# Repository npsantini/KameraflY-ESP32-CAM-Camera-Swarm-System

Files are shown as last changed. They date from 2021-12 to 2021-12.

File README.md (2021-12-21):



# KameraflY

<table width="100%">
    <tr>
	    <td width="33.33%"></td>
	    <td width="33.33%">
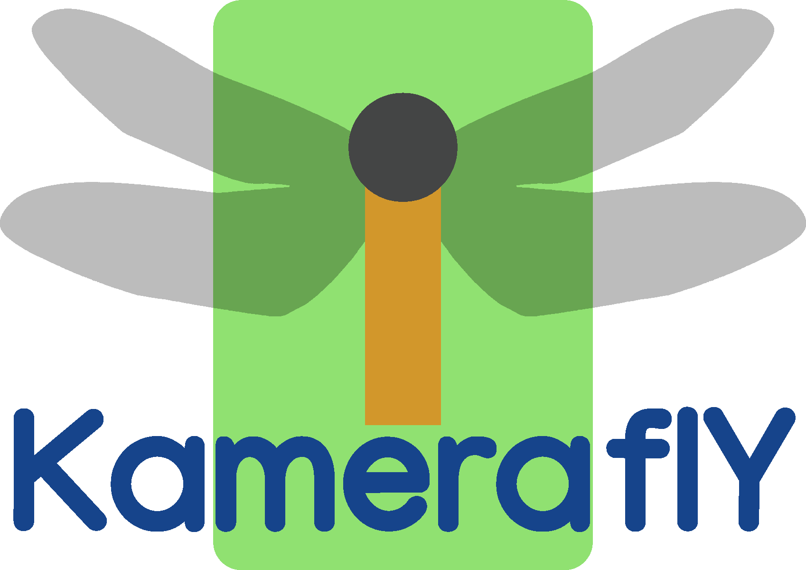
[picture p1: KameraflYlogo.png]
camerafly logo
		    
	    </td>
	    <td width="33.33%"></td>
    </tr>
</table>

## Contents
- <a href="#firmware">Overview</a>
- <a href="#firmware">ESP32-CAM Firmware</a>
    - <a href="#arduino">Arduino IDE</a>
    - <a href="#libraries">Libraries</a>
    - <a href="#functions">Functions</a>
    - <a href="#firmware-improvement">Potential Improvements</a>
- <a href="#blynk">Blynk App</a>
    - <a href="#setup">Setup</a>
    - <a href="#components">Components</a>
    - <a href="#blynk-improvement">Potential Improvements</a>
- <a href="#web">Web App</a>
    - <a href="#requirements">Requirements</a>
    - <a href="#web-improvement">Potential Improvements</a>
- <a href="#pcb">PCB Info</a>
	- <a href="#pcb-improvement">Potential Improvements</a>
- <a href="#housing">Housing</a>
	- <a href="#housing-improvement">Potential Improvements</a>
- <a href="#parts">Parts</a>
	- <a href="#partslist">Parts List</a>
	- <a href="#parts-improvement">Potential Improvements</a>

<hr>
<!-- Overview -->

### Overview
<hr>
<p>
Our current ESP32-CAM camera swarm is a completly wireless swarm that is capable of caturing synchronized images down to 10ms.
The system we have created allows a user to use and Android or iOS app to control the camera swarm. When images are captured they 
are sent to a web server where all of the images can be downloaded at once. The images collected from the web server can be used 
in many different applications like 3D modeling or for use in 3D point cloud software.</p>

<p>Each of our completed modules costs only $13.43. When scaled to 256 modules the cost $6.96 per module. This makes this camera swarm 
an extremely cost effective tool that is a lot more accessible than traditional DSLR focused camera swarms.</p>

<p align="right">(<a href="#top">back to top</a>)</p>
<hr>
<!-- ESP32-CAM Firmware -->

### ESP32-CAM Firmware
<hr>
The ESP32-CAM modules in our swarm were all programmed to work with the Blynk app. This was mainly due to time constraints and the ease of use. It is setup in a way to perform only a few actions like connect to the Blynk app, save images to an SD card, upload an image via FTP, and live stream video. There are improvements that can be made and it's far from perfect. It satisfied our engineering requirements, which is all we had set out to accomplish.

I encourage anyone that would like to continue this to fork this repository or make pull requests.

#### Arduino IDE
The Arduino IDE is what was used for ease of use. It is possible to also use <a href="https://platform.io" target="_blank">PlatformIO</a> although we have not tested it.
It's important to include all of the libraries that you will see in the next section. It is also important that in the change the information in the <a href="#">secrets.h</a> file.
```C++
// secrets.h file
#define SECRET_SSID "INSERT WIFI SSID HERE"
#define SECRET_PASSWORD "INSERT WIFI PASSWORD HERE"

#define SECRET_FTP_SERVER "INSERT FTP SERVER IP ADDRESS HERE"
#define SECRET_FTP_USERNAME "INSERT FTP USERNAME HERE" // ex. user@example.com
#define SECRET_FTP_PASSWORD "INSERT FTP PASSWORD"
```

#### Libraries
In order to include all of the necessary libraries for the ESP32-CAM's you need to 
add the following additional board manager in the Arduino IDE under `File > Preferences`:
<br>
```
https://raw.githubusercontent.com/espressif/arduino-esp32/gh-pages/package_esp32_index.json
```

##### Included packages from the source above:
- SD_MMC
- WebServer
- EEPROM
- FS
- WiFi
- And more.

You might have conflicting wifi libraries. You will have to fix this by removing one of the libraries that the error message lists.

##### Libraries in Arduino Library Manager
- Blynk (Volodymyr Shymanskyy) v0.6.1
- esp32_ftpclient (Leonardo Bispo) v0.1.4
- SD (Arduino) v1.2.4
- Time (Paul Stoffregen) v1.6.1

#### Functions
- Live Stream Functions (Anatoli Arkhipenko, https://github.com/arkhipenko/esp32-cam-mjpeg)
	- handle_jpg_stream(void)
	- handle_jpg()
	- handleNotFound()
- SD Card Functions (Rui Santos, https://RandomNerdTutorials.com/esp32-cam-take-photo-save-microsd-card)
	- SD_MMC.begin() // Check to see if sd card is mounted
	- SD_MMC.cardType() // Check card type
- FTP Functions
	- FTP_upload(void)
- Main Logic Functions
	- setup()
	- loop()
	- take_picture()
- Blynk Functions/Methods
	- Blynk.run()
	- BLYNK_CONNECTED()
	- BLYNK_WRITE(V5)
	- BLYNK_WRITE(V10)
	- BLYNK_WRITE(V12)
	- BLYNK_WRITE(V14)
- Misc. Functions
	- deep_sleep()
	- ipAddress2String(const IPAddress& ipAddress)

#### Potential Improvements

<p>
This firmware for the ESP32-CAM is not perfect. We encourage people make improvements as they see fit. Most of the code is to be specifically used with the Blynk Legacy mobile app. If you wish to use your own app it would need to be changed substantially.
</p>
<p>
One big improvement would be programming the ESP32-CAM modules to take an image at a specified time. This is something we were not able to accomplish with the current version of the Blynk app, but will be coming soon as dicussed in more detail below.
</p>

<p align="right">(<a href="#top">back to top</a>)</p>
<hr>

<!-- Blynk App -->

### Blynk App
<hr>
<p>
We chose to use the Legacy Blynk app to control our ESP32-CAM camera swarm. It's not a perfect solution, but is much more convenient than writing your own app to fulfill the same functionality. There are a lot of great things you can do with the Blynk app, however we have chosen to use what we believe to be the bare essentials necessary to control and effectively use the camera swarm.
</p>

#### Setup
<p>Below are some images of the basic setup of each ESP32-CAM module and how to add all of the modules to one tag. In this case, we named the tag "All",
but you could name it whatever you like. Having all of the modules with the same tag allows us to use one button to capture all of the images from each of the cameras in the camera swarm simultaneously.</p>

<table>
    <tr>
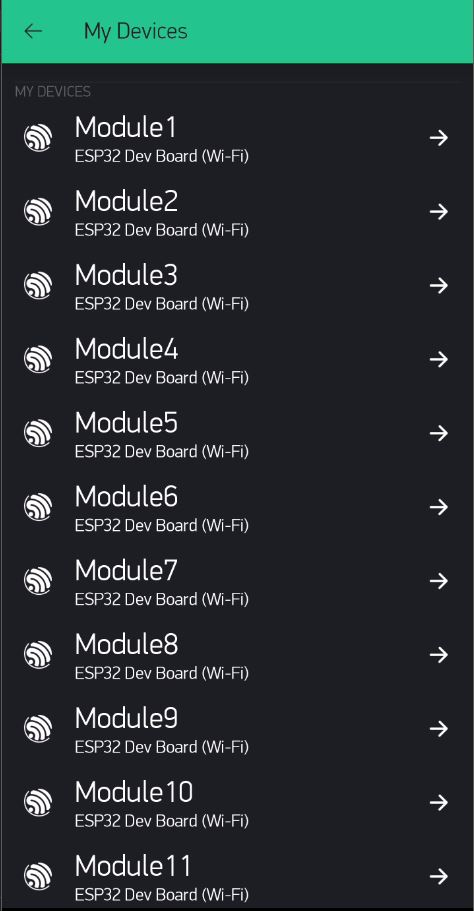
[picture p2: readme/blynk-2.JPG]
        <td width="20%"></td>
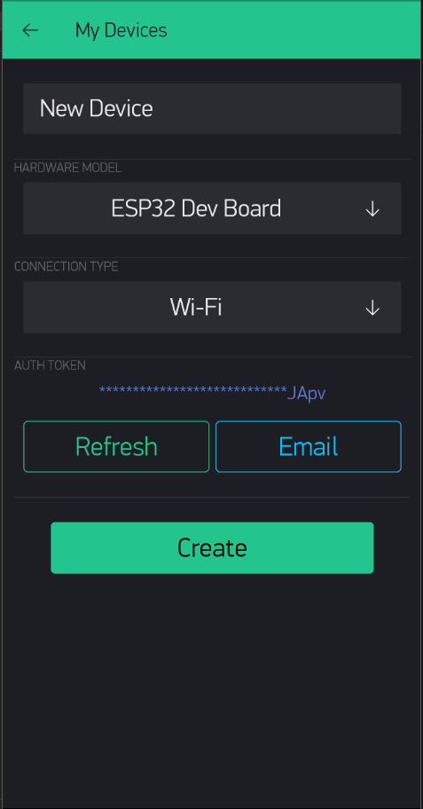
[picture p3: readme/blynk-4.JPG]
        <td width="20%"></td>
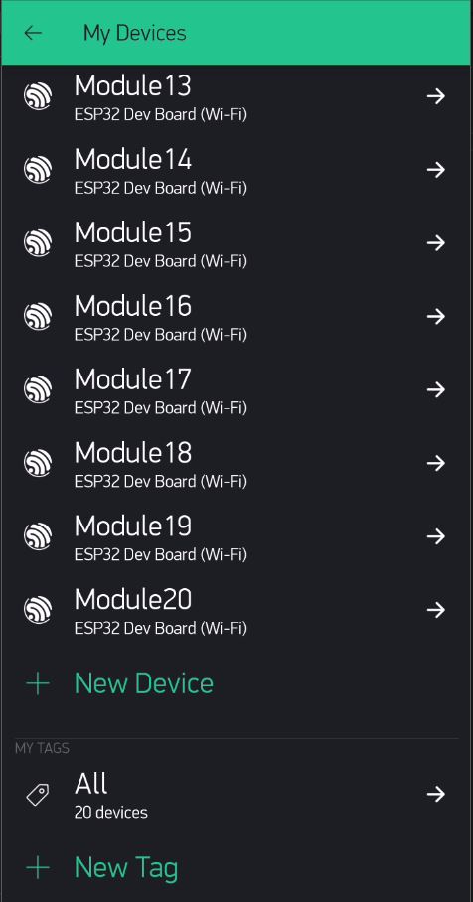
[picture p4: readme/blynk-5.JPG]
        <td width="20%"></td>
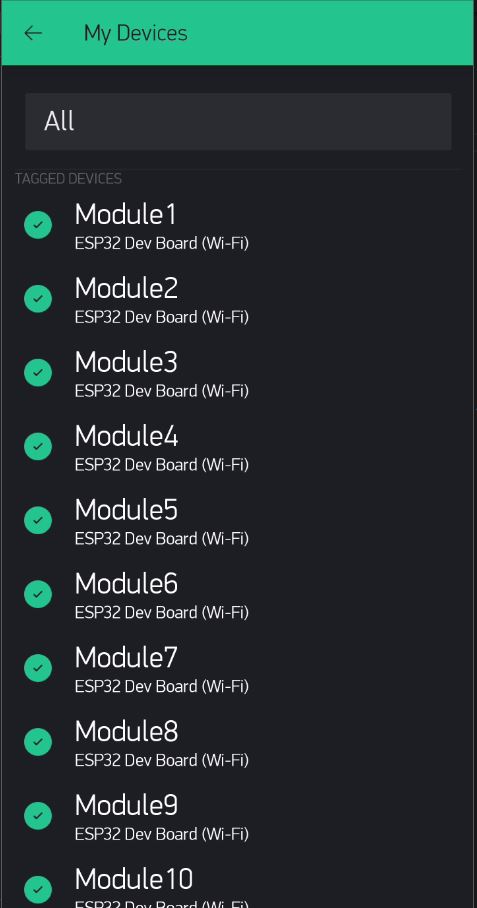
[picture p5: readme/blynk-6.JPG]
        <td width="20%"></td>
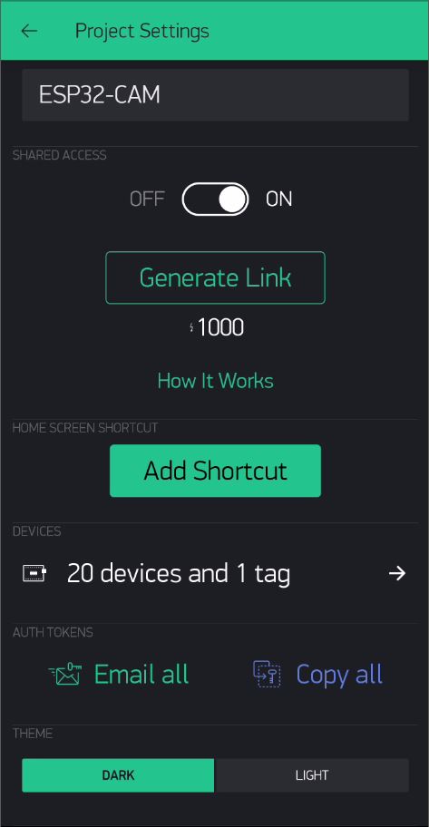
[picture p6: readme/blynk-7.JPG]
        <td width="20%"></td>
    </tr>
    <tr>
	    <td valign="top" width="20%">
		    <p>- Go to "My Devices."</p>
		    <p>- Scroll down and click "+ New Device."</p>
	    </td>
	    <td valign="top" width="20%">
		    <p>- Name the module (numbers help identify the module later).</p>
		    <p>- Select "ESP32 Dev Board.</p>
		    <p>- Choose "Wi-Fi".</p>
		    <p>- Click "Create".</p>
	    </td>
	    <td valign="top" width="20%">
		    <p>- You will then see a list of modules that you have created.</p>
		    <p>- Now create a new tag by clicking "+ New Tag"</p>
	    </td>
	    <td valign="top" width="20%">
		    <p>- Name the tag "All"</p>
		    <p>- Once created check off all of the modules you want to add to the tag.</p>
	    </td>
	    <td valign="top" width="20%">
		    <p>- In the project settings click "Email all" to get all of the Authorization tokens that you will need to include in the firmware.</p>
	    </td>
    </tr>
</table>
<p>
The most important part of the setup is that you get all of the Authorization tokens (emailing them from the app is easiest) and add them to the section of code below. Make sure you only have one authorization token uncommented at a time. For each ESP32-CAM that you program you need to uncomment a new token and change the `cam_module` number to the current module you are using. This will allow you to identify which module each picture came from and helps with troubleshooting the modules.
</p>

```c++
String cam_module = "4"; 
//char auth[] = "MODULE 1 AUTH TOKEN HERE"; //1
//char auth[] = "MODULE 2 AUTH TOKEN HERE"; //2
//char auth[] = "MODULE 3 AUTH TOKEN HERE"; //3
char auth[] = "MODULE 4 AUTH TOKEN HERE"; //4
//char auth[] = "MODULE 5 AUTH TOKEN HERE"; //5
// etc...
```

#### Components
<p>While we chose to use these specific components to accomplish what we needed to accomplish, you can choose what you you need and can remove the rest. Just make sure to remove the code for components that you aren't using.</p>
<table>
	<tr>
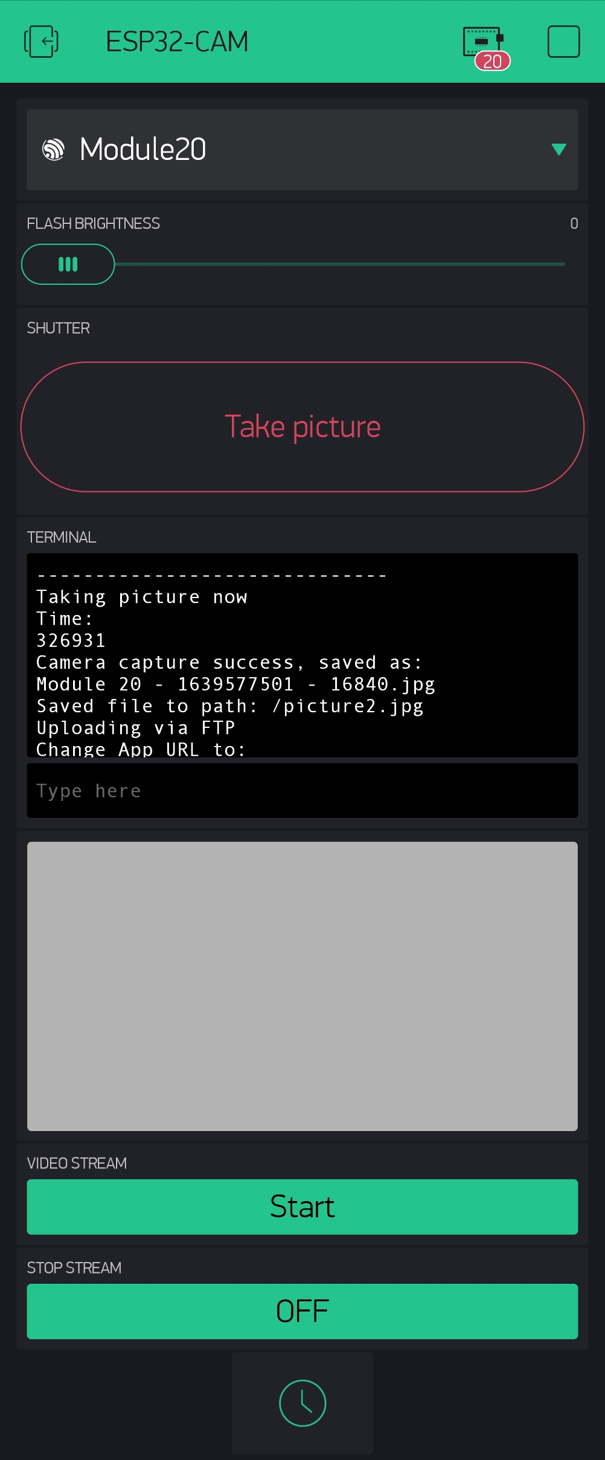
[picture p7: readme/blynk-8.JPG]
		<td width="40%"></td>
		<td width="60%">
	
- Device Selector

- Slider
	- Target: selector
	- Output: 0 - 4
	- Pin: V10

- Button
	- Target: All tag
	- Output: 0 - 1
	- Pin: V5

- Terminal
	- Target: Selector
	- Add Newline: Yes
	- Autoscroll: Yes
	- Pin: V0

- Video Stream
	- Target: Selector
	- URL: 
	- Pin: V13

- Styled Button (Video Stream Start)
	- Target: Selector
	- Output: 0 - 1
	- Pin: V12

- Styled Button (Video Stream Stop)
	- Target: All tag
	- Output: 0 - 1
	- Pin: V14

- Real-time Clock
	- Timezone: (Whatever you wish to use)

		</td>
	</tr>
</table>

#### Potential Improvements
<p>There are improvements coming to the Blynk app that will allow for all of the components to be controlled via the Blynk Cloud web dashboard. This would greatly improve the usability and would elimintate the need to use a mobile phone. Being able to send specific signals such as a time in order to schedule an image capture would greatly improve the synchronization times of the images. We have been told that a lot of this functionality should arrive in Q2 2022.
</p>
<p>Until then we highly recommend using the Legacy Blynk app and not the Blynk IoT app.</p>

<p align="right">(<a href="#top">back to top</a>)</p>
<hr>

<!-- Web App -->

### Web App
<hr>
<p>
The web app that we have included in this is a PHP site displays the last images captured as well as images by each module. It is very basic, but allows you to collect all of the images in a zip file which is extremely useful when you need to import the images in other programs.
</p>

<p>
The login system is something that was added to make sure that people couldn't see the images that were captured unless they had a login. For this specific demo we have a default user and an admin user. Only the admin user has the ability to delete images.
</p>

<p>
<b>It is highly recommended that you change these usernames and passwords!</b>
</p>

- Default User
	- Username: user
	- Password: password

- Admin User
	- Username: admin
	- Password: password

<p>The usernames and passwords are defined as seen below in an array in the `login.php` page and should be changed.</p>

```PHP
$logins = array('admin' => 'password','user' => 'password');
```

#### Requirements

- Web Server
	- Apache
	- PHP v7.0 (or later)
- Optional
	- Web hosting
	- Domain name

#### Potential Improvements
<p>A better way of sorting the images would make this a lot better. Right now it relies on the file name of the images to sort them. This is obviously not ideal.</p>

<p align="right">(<a href="#top">back to top</a>)</p>
<hr>

<!-- PCB Info -->

### PCB Info
<hr>
<table>
	<tr>
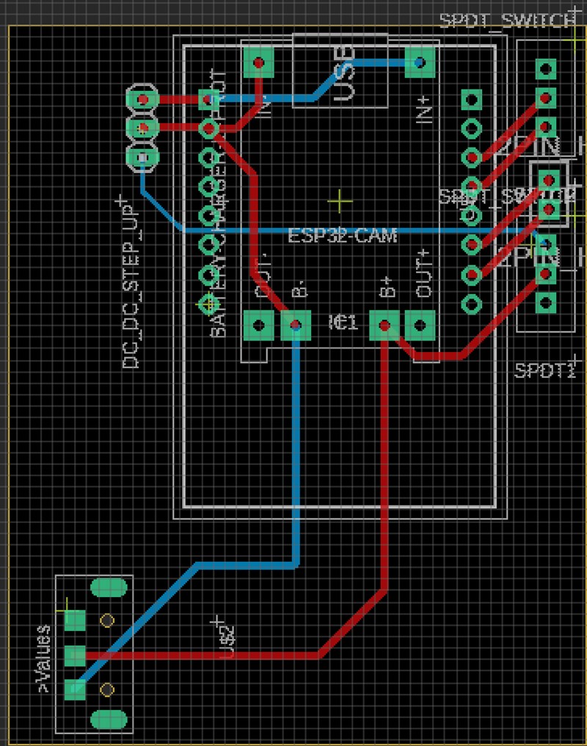
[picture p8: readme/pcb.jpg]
		<td width="25%"></td>
		<td width="75%">
			<p>The PCB subsystem was created to connect all components used for each module together so they are compact, and set up and transport easily. The PCB reduces the need for wires allowing the casing to be smaller. The PCB has dimensions of 50mm X 55mm. There is a switch in the circuit that will turn power off to the ESP32-CAM saving power.</p>
			<p>The routing on the board connects the output of the battery charger to the battery and then to the boost converter. This will increase the voltage from ~3.7V, the voltage of the battery, to 5V, a useful voltage for the ESP32-CAM. This circuit is also ran through a switch that allows the unit to be put in standby mode to save charge. Another switch is connected to two pins of the ESP32-CAM so they can be shorted out to place the camera in programming mode. The 2-pin header is to provide access to the camera for programming purposes.</p>
		</td>
	</tr>
</table>

#### Potential Improvements

<p>
We went through 5 different iterations of the PCB which can be found in the `pcb-shematic` folder. Many of the changes from version to version were to make the footprint as small as possible and to make changes to the battery connector. The battery connector is a part that likely needs to be changed with a better connector for the battery we used. Since we couldn't find the exact battery connector we made our own part in Autodesk Eagle.
</p>
<p>
It's highly recommended that you use these PCB schematics as a starting point for your own, unless you use the exact same parts as we did.
</p>
<p align="right">(<a href="#top">back to top</a>)</p>
<hr>

<!-- Housing -->

### Housing
<hr>

<table>
	<tr>
		<td width="100%">
			<p>The housing is designed so the ESP32-CAM modules can be easily transported and handled comfortably. The housing includes at least 2 different types of mounting to allow for a variety of ways to setup the system. The two chosen were a Keyhole hanger and two tripod mounts. The case allows for access to the removable battery, the removable SD Card, the charging port for the battery, and the various switches used for power and low power mode. The most recent housing is 72 x 58 x 25 mm which is considered "handheld" and fits the components comfortably.
			</p>
			<p>The drafts of the housing and Autodesk Inventor files can be found in the `ESP32-CAM Housing` folder. 
			</p>
		</td>
	</tr>
	<tr>
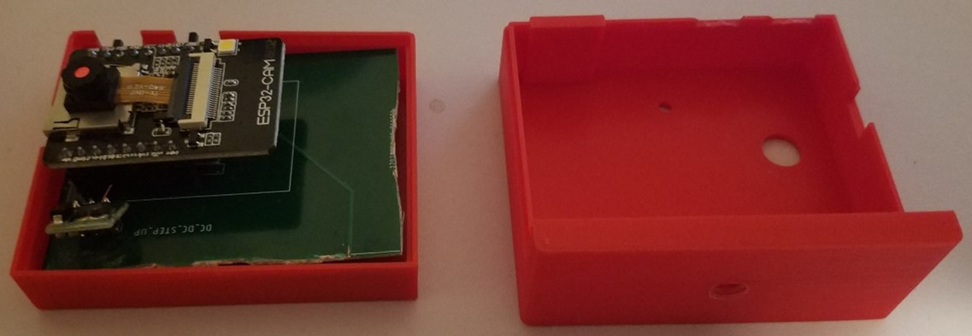
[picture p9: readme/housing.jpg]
		<td width="50%"></td>
	<tr>
</table>

#### Potential Improvements

<p>
The tolerances are really tight with the PCB. This is intentional as it allows the battery to fit against the leaf springs in the battery connector. It is however not as reliable as we would have liked it to be and improvements to the how the battery sits in the housing can and probably should be made.
</p>
<p>
The tolerances between the two pieces of the case are also tight and will likely vary with different 3D printers. This is an area which may need improvement.
</p>

<p align="right">(<a href="#top">back to top</a>)</p>
<hr>

<!-- parts -->

### Parts
<hr>
<p>Below is a parts list for all of the different parts required to make the completed product. Most of the items can be found on Amazon, but some are specialty parts like the PCB and battery connector.</p>

<table>
	<tr>
		<th>Device</th>
		<th>Manufacturer</th>
		<th>Item</th>
	</tr>
	<tr>
		<td><a href="https://amzn.to/3pZpIXn" target="_blank">ESP32-CAM</a></td>
		<td>espressif</td>
		<td>Camera Module</td>
	</tr>
	<tr>
		<td><a href="https://amzn.to/3GQk8xg" target="_blank">BP-70A Battery</a></td>
		<td>Kastar</td>
		<td>3.7v Lithium-Ion Camera Battery</td>
	</tr>
	<tr>
		<td><a href="https://amzn.to/3GPXchW" target="_blank">DC-DC Step Up Power Module</a></td>
		<td>Weewooday</td>
		<td>Boost Converter</td>
	</tr>
		<tr>
		<td><a href="https://amzn.to/33BLKIn" target="_blank">TP4056 Charging Module</a></td>
		<td>Weewooday</td>
		<td>Battery charging circuit</td>
	</tr>
	<tr>
		<td><a href="https://amzn.to/3mbGQbh" target="_blank">1.75mm PLA Filament</a></td>
		<td>SUNLU</td>
		<td>Product Housing</td>
	</tr>
	<tr>
		<td><a href="https://amzn.to/3GG7lO2" target="_blank">2 Position Slide Switch</a></td>
		<td>Tnuocke</td>
		<td>Power/Programming switch</td>
	</tr>
	<tr>
		<td><a href="https://jlcpcb.com" target="_blank">Custom PCB</a></td>
		<td>jlcpcb.com</td>
		<td>PCB for each module</td>
	</tr>
	<tr>
		<td><a href="https://amzn.to/3mbpr2y" target="_blank">8-Pin Socket Connectors</a></td>
		<td>Comidox</td>
		<td>Headers for ESP32-CAM</td>
	</tr>
		<tr>
		<td><a href="https://www.te.com/usa-en/product-1746142-1.html" target="_blank">3-Pin Leaf Type Connector (1746142-1)</a></td>
		<td>TE Connectivity</td>
		<td>Battery Connector</td>
	</tr>
</table>

#### Potential Improvements

<p>The boost converter that we used easy extremly sensitive to heat therefor hard to solder without destroying it. It is recommended that is be switched out for a more durable and reliable boost converter.</p>
<p>
The battery connector is not meant to be used with the specific battery we are using. It is close to being the right one and will work, but it is recommneded that you find a better connector if you plan to use that same battery.
</p>

<p align="right">(<a href="#top">back to top</a>)</p>

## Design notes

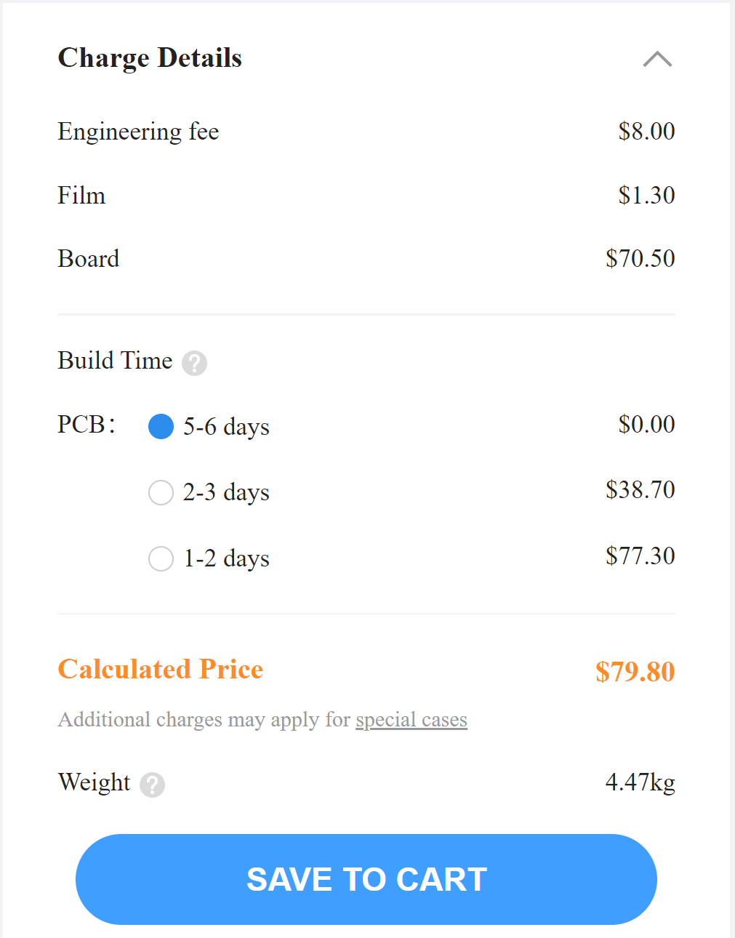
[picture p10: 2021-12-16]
pcb-schematic/Second prototype/Screenshot (6).png

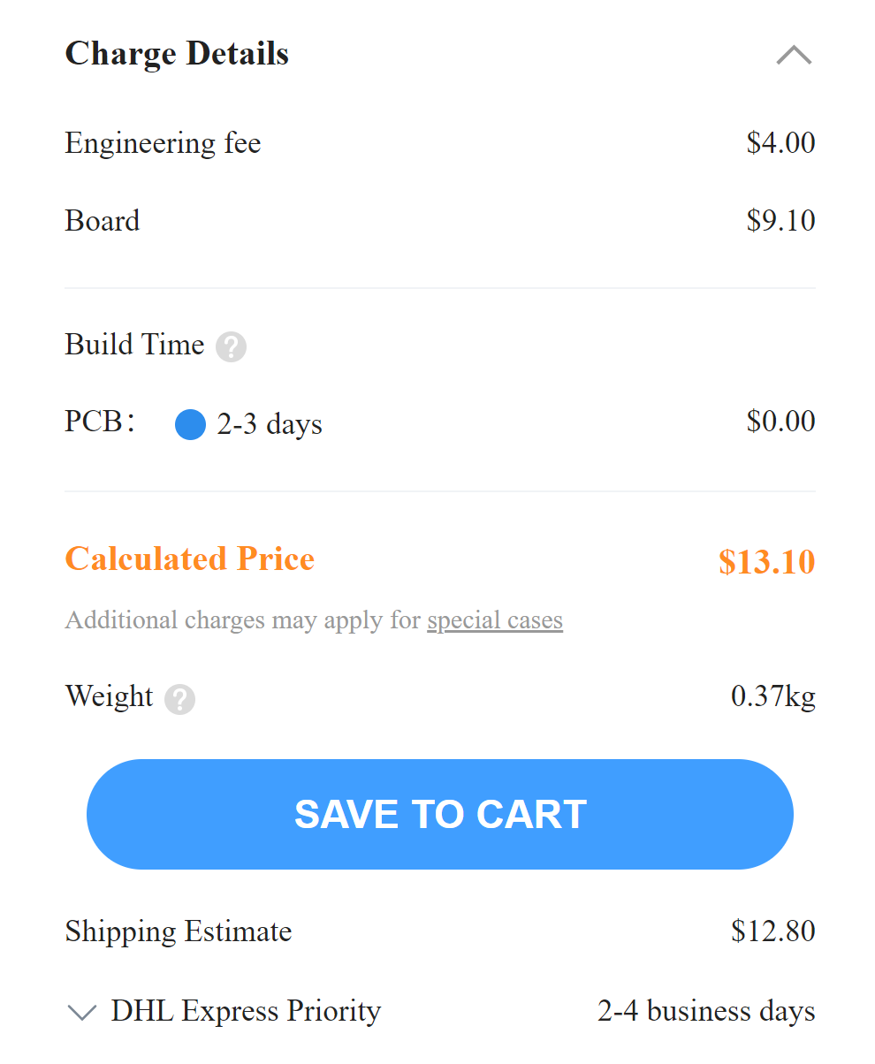
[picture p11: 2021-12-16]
pcb-schematic/Second prototype/Screenshot (7).png

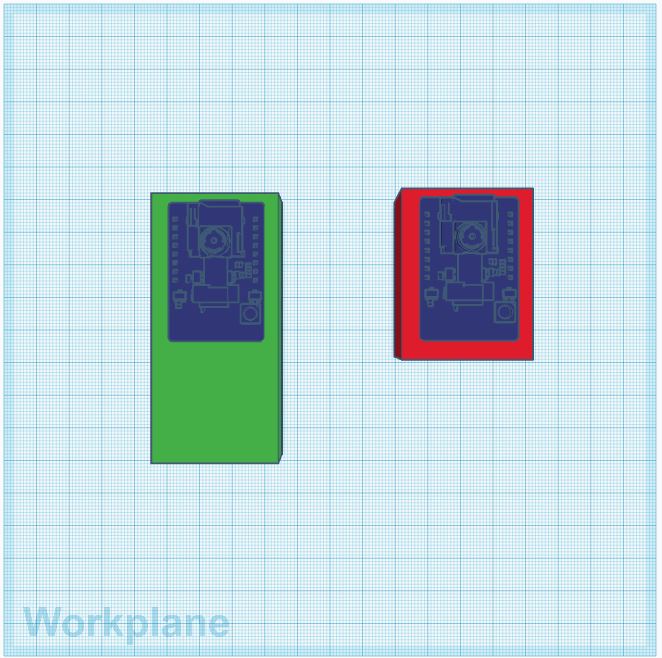
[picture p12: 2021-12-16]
misc/Package-Decision-Top.JPG

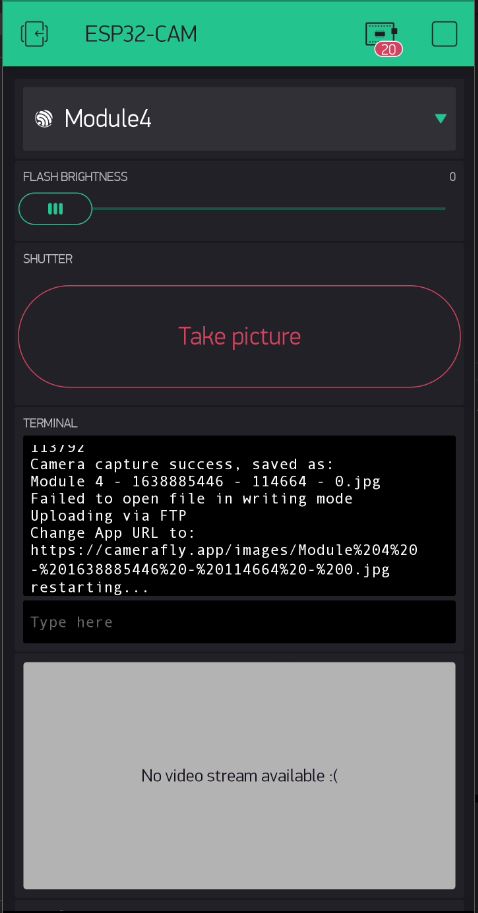
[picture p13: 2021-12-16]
readme/blynk-1.JPG

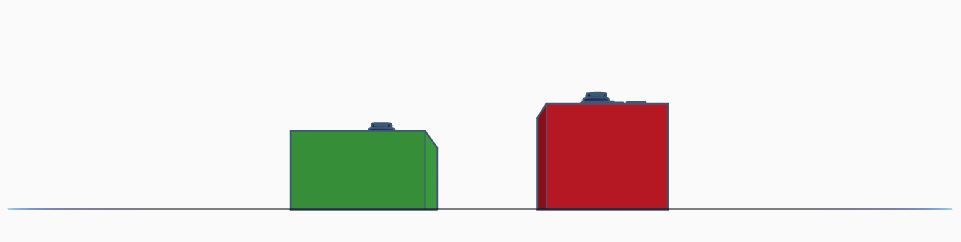
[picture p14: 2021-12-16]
misc/Package-Decision-Front.JPG

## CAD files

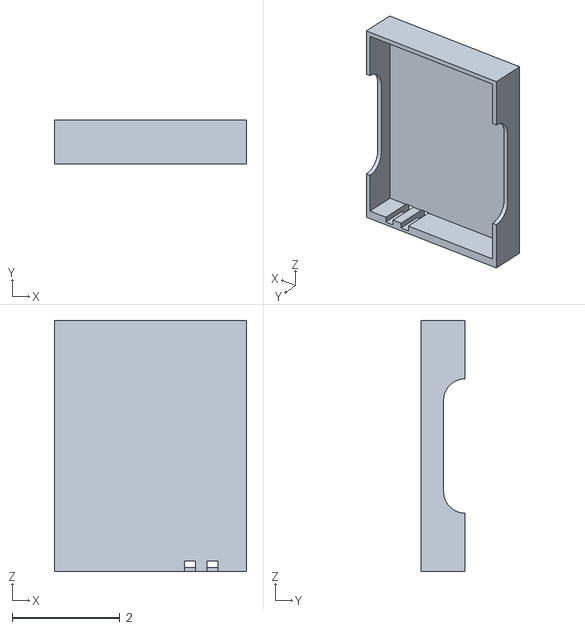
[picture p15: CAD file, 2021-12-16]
3D-Printing/battery-cover-v2.stl
3.58 x 0.82 x 4.67

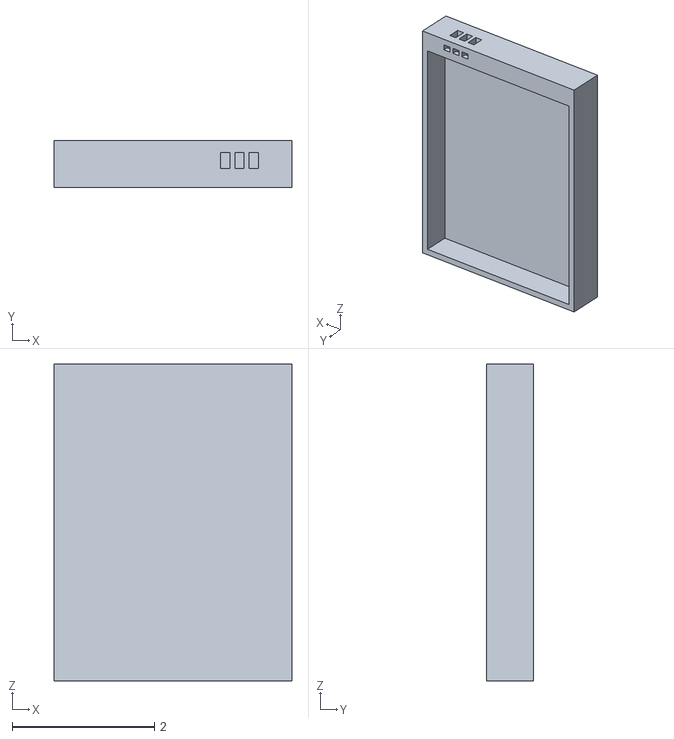
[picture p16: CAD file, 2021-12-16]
3D-Printing/battery-holder.stl
3.34 x 0.66 x 4.45

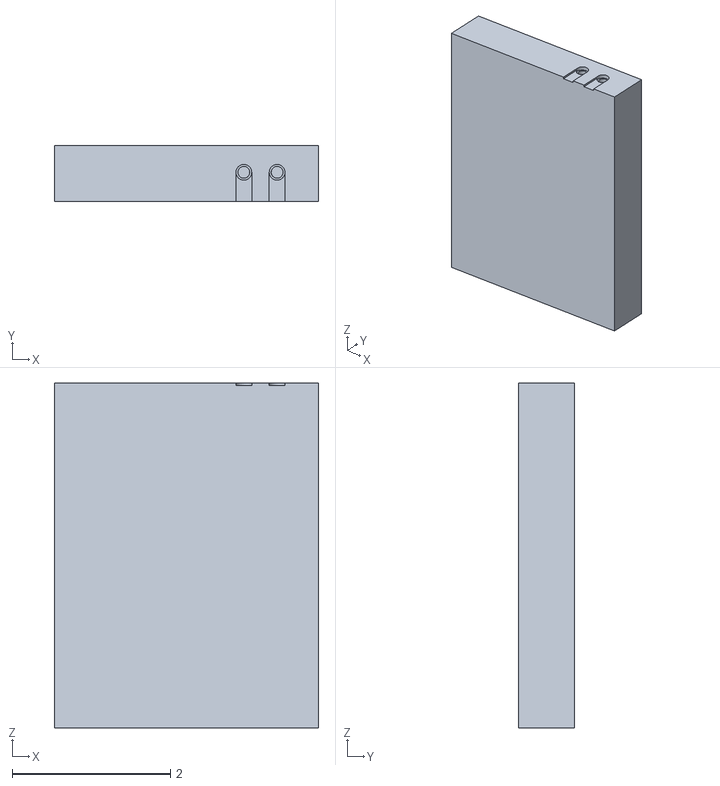
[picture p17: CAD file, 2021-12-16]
3D-Printing/battery-holder-v2.stl
3.34 x 0.71 x 4.36

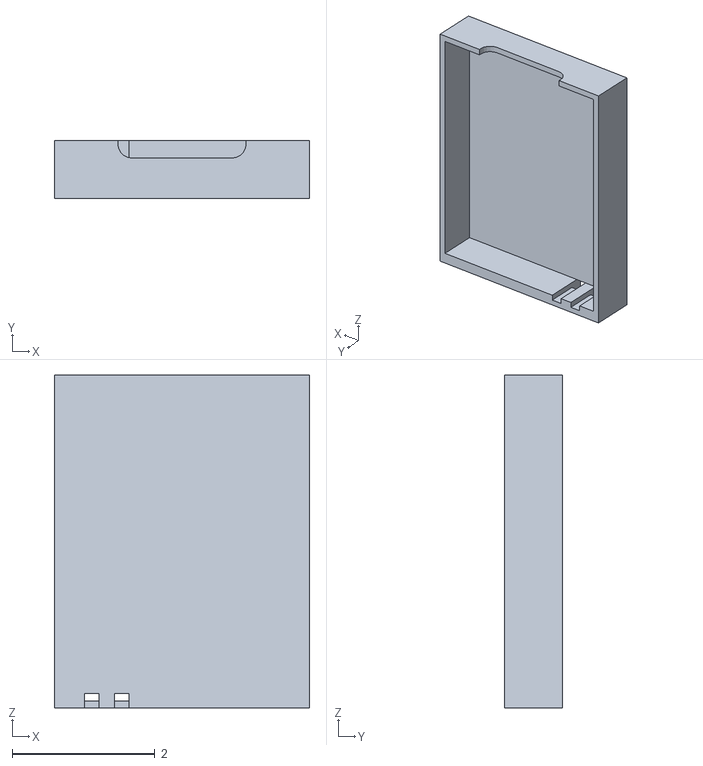
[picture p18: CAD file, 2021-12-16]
3D-Printing/battery-cover.stl
3.58 x 0.82 x 4.67

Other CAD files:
3D-Printing/OldVersions/battery-cover.0005.ipt
3D-Printing/OldVersions/battery-holder-v2.0003.ipt
3D-Printing/battery-cover.ipt
3D-Printing/battery-holder-v2.ipt
3D-Printing/battery-holder.ipt
ESP32-CAM Housing/ESP32CAM Housing/Shell 1 bottom.ipt
ESP32-CAM Housing/ESP32CAM Housing/Shell 1 bottom_MIR.ipt
ESP32-CAM Housing/ESP32CAM Housing/Shell 2 bottom.ipt
ESP32-CAM Housing/ESP32CAM Housing/Shell 2 top.ipt
ESP32-CAM Housing/ESP32CAM Housing/Shell 3 bottom.ipt
ESP32-CAM Housing/ESP32CAM Housing/Shell 3 top.ipt
ESP32-CAM Housing/ESP32CAM Housing/Shell 4 bottom.ipt
ESP32-CAM Housing/ESP32CAM Housing/Shell 4 top.ipt
ESP32-CAM Housing/ESP32CAM Housing/Shell 5 bottom.ipt
ESP32-CAM Housing/ESP32CAM Housing/Shell 5 top.ipt
ESP32-CAM Housing/ESP32CAM Housing/Shell Draft 1.iam
ESP32-CAM Housing/ESP32CAM Housing/Shell draft 4.iam

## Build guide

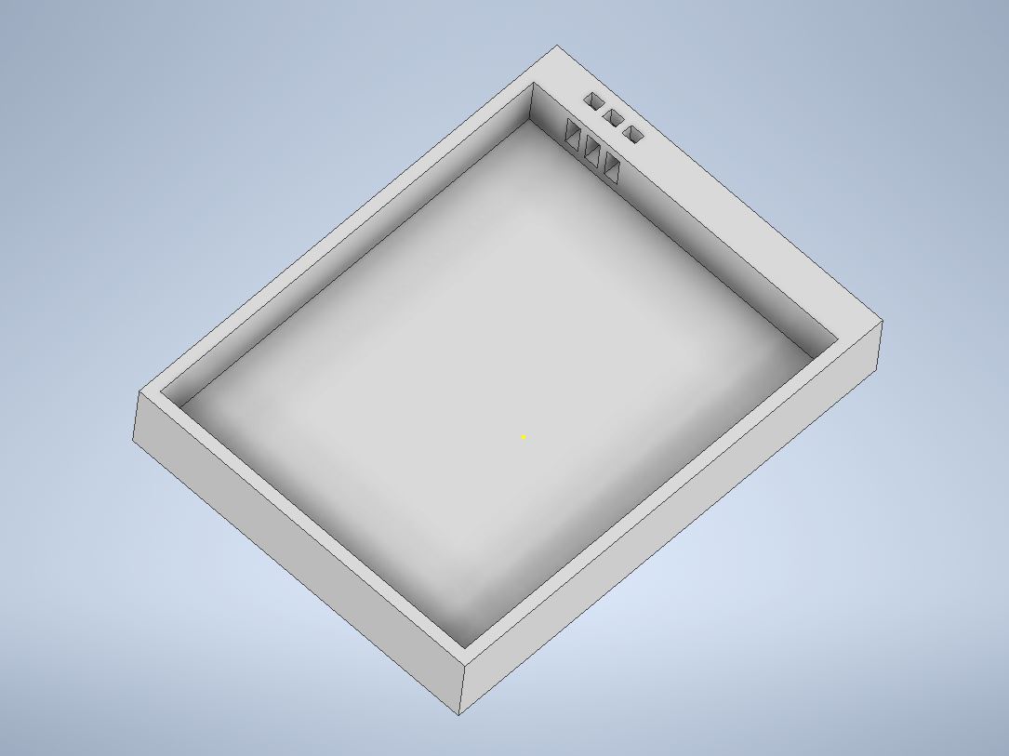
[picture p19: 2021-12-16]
3D-Printing/battery-holder-1.JPG

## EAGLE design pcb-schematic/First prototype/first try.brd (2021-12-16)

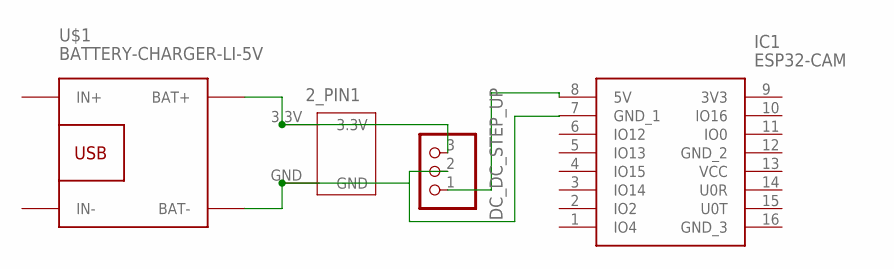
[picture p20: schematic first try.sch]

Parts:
2_PIN1: 2_PIN_HEADER
DC_DC_STEP_UP: PINHD-1X3; 1X03
IC1: ESP32-CAM; ESP32CAM
U$1: BATTERY-CHARGER-LI-5V

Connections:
unnamed: 2_PIN1.GND, DC_DC_STEP_UP.2, IC1.7 (GND_1), U$1.BAT-
unnamed: 2_PIN1.3.3V, DC_DC_STEP_UP.3, U$1.BAT+
unnamed: DC_DC_STEP_UP.1, IC1.8 (5V)

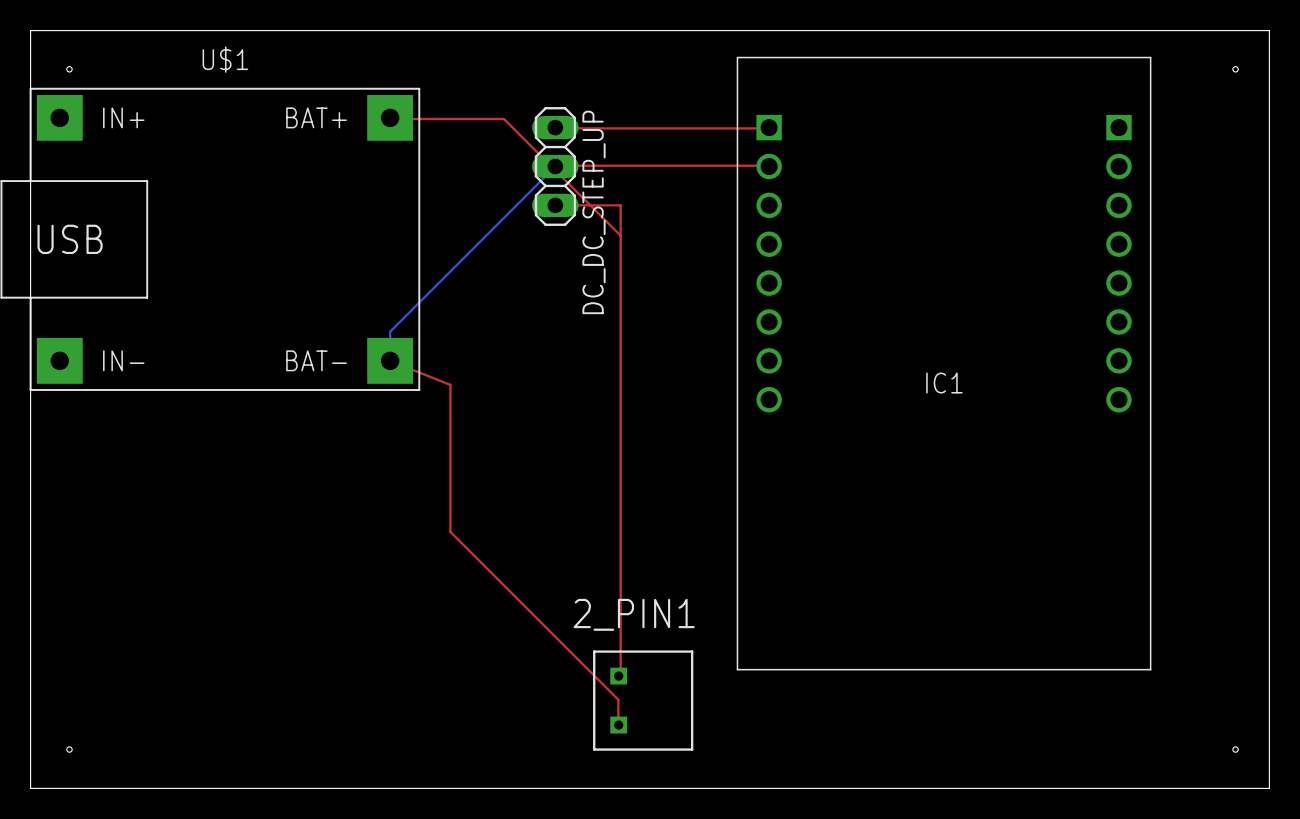
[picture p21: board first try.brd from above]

Board: 2 copper layers, 81.0 x 49.5 mm, 4 parts (0 on the bottom side), 3 nets.

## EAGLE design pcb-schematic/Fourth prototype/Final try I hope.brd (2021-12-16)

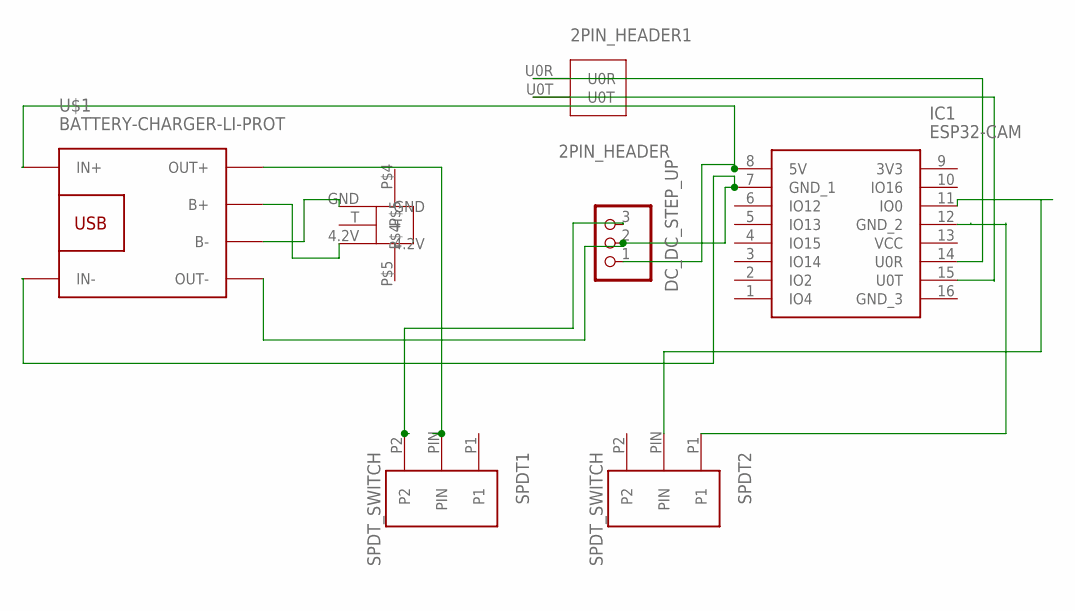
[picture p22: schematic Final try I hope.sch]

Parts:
2PIN_HEADER1: 2PIN_HEADER
DC_DC_STEP_UP: PINHD-1X3; 1X03
IC1: ESP32-CAM; ESP32CAM
SPDT1, SPDT2: SPDT_SWITCH
U$1: BATTERY-CHARGER-LI-PROT
U$2: BATTERY_CONNECTOR

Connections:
unnamed: DC_DC_STEP_UP.1, IC1.8 (5V), U$1.IN+
unnamed: DC_DC_STEP_UP.3, SPDT1.P2
unnamed: U$1.B-, U$2.GND
unnamed: U$1.B+, U$2.4.2V
unnamed: IC1.11 (IO0), SPDT2.PIN
unnamed: IC1.12 (GND_2), SPDT2.P1
unnamed: 2PIN_HEADER1.U0R, IC1.14 (U0R)
unnamed: 2PIN_HEADER1.U0T, IC1.15 (U0T)
unnamed: SPDT1.PIN, U$1.OUT+
unnamed: DC_DC_STEP_UP.2, IC1.7 (GND_1), U$1.IN-, U$1.OUT-

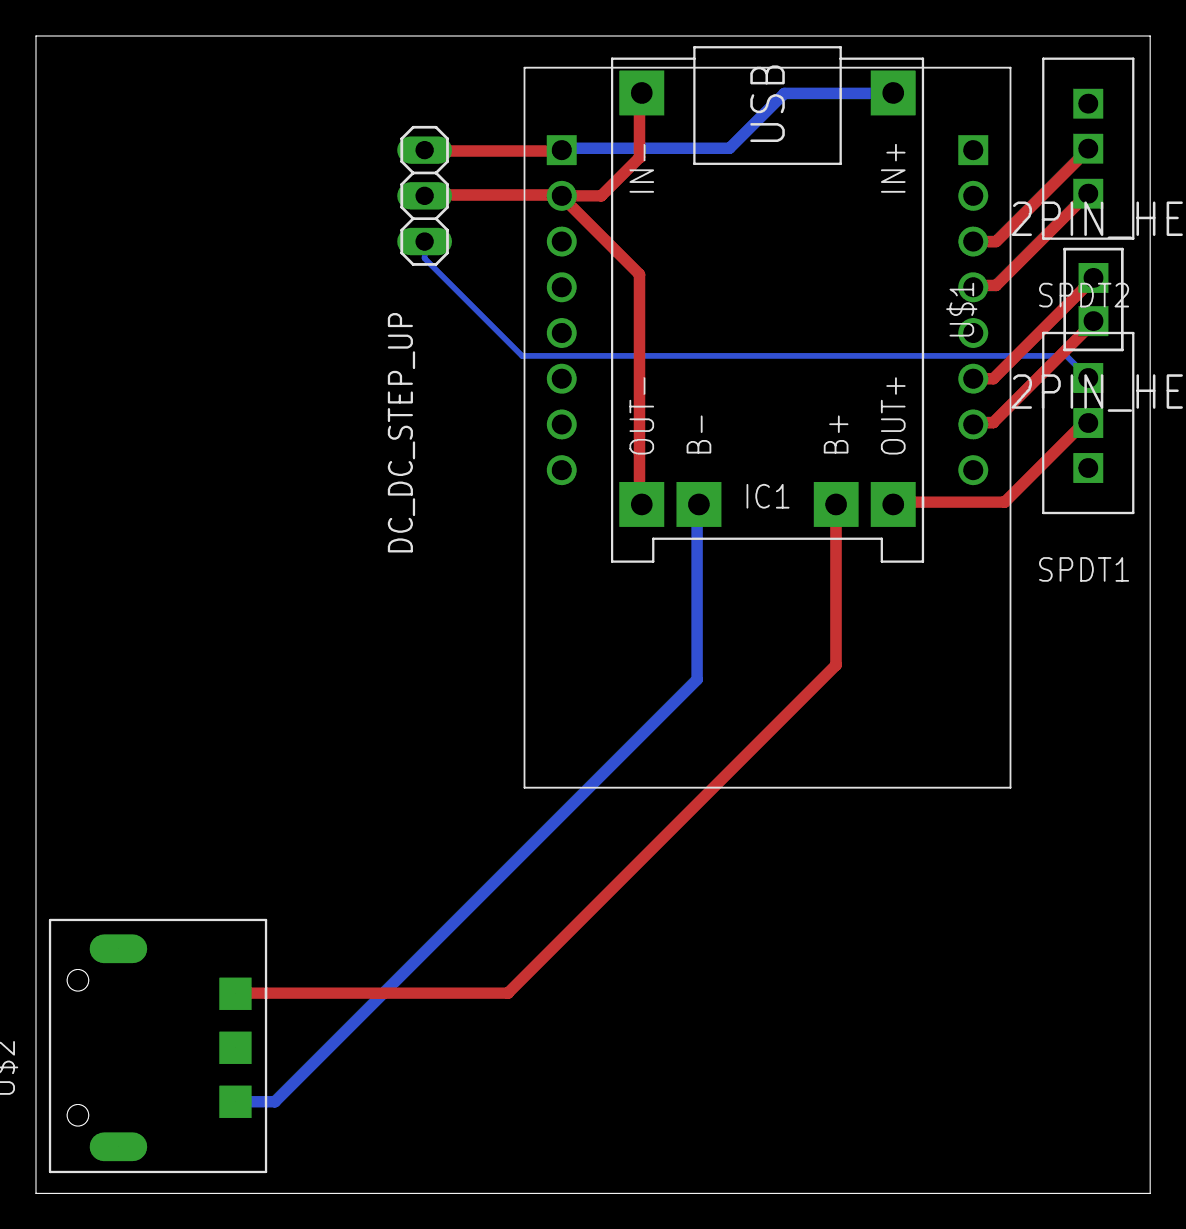
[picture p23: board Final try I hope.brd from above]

Board: 2 copper layers, 61.9 x 64.3 mm, 7 parts (0 on the bottom side), 10 nets.

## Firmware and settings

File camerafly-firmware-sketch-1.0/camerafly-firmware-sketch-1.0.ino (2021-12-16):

/***************************************************************************************************************
FTP Credit to Leonardo Bispo (https://github.com/ldab/ESP32-CAM-Picture-Sharing)
Live Stream Functions Credit to Anatoli Arkhipenko (https://github.com/arkhipenko/esp32-cam-mjpeg)
SD Card Functions Credit to Rui Santos (https://RandomNerdTutorials.com/esp32-cam-take-photo-save-microsd-card)
****************************************************************************************************************/
#include "Arduino.h"
#include "src/secrets.h"
/* Comment this out to disable prints and save space */
#define BLYNK_DEBUG
#define BLYNK_PRINT Serial
#define DEBUG_ESP

// Blynk related libraries
#include <WiFi.h>
#include <WiFiClient.h>
#include <BlynkSimpleEsp32.h>
#include <TimeLib.h>
#include <WidgetRTC.h>

// Live stream related libraries
#include "src/OV2640.h"
#include <WebServer.h>

#include "esp_camera.h"
#include "esp_timer.h"
#include "img_converters.h"

// SD Card related libraries
#include "FS.h"
#include "SD_MMC.h"
#include <EEPROM.h>

// In BLYNK add a device (ESP32 DEV, WIFI) and copy the authentication token for each unit
// 
// Chose the module you are programming and uncomment the auth token for that module
String cam_module = "4"; 
//char auth[] = "MODULE 1 AUTH TOKEN HERE"; //1
//char auth[] = "MODULE 2 AUTH TOKEN HERE"; //2
//char auth[] = "MODULE 3 AUTH TOKEN HERE"; //3
char auth[] = "MODULE 3 AUTH TOKEN HERE"; //4
//char auth[] = "MODULE 5 AUTH TOKEN HERE"; //5
// etc...

// Your WiFi credentials.
char ssid[] = SECRET_SSID;
char pass[] = SECRET_PASSWORD;

// FTP Client Lib
#include "ESP32_FTPClient.h"

// FTP Server credentials
char ftp_server[] = SECRET_FTP_SERVER;
char ftp_user[]   = SECRET_FTP_USERNAME;
char ftp_pass[]   = SECRET_FTP_PASSWORD;

// SD card initialize variables
int pictureNumber = 0; // Initialize picture number for SD Card
#define EEPROM_SIZE 1 // define the number of bytes you want to access

// Live stream server setup
#define CAMERA_MODEL_AI_THINKER
OV2640 cam;
WebServer server(80);

const char HEADER[] = "HTTP/1.1 200 OK\r\n" \
                      "Access-Control-Allow-Origin: *\r\n" \
                      "Content-Type: multipart/x-mixed-replace; boundary=123456789000000000000987654321\r\n";
const char BOUNDARY[] = "\r\n--123456789000000000000987654321\r\n";
const char CTNTTYPE[] = "Content-Type: image/jpeg\r\nContent-Length: ";
const int hdrLen = strlen(HEADER);
const int bdrLen = strlen(BOUNDARY);
const int cntLen = strlen(CTNTTYPE);

void handle_jpg_stream(void) {
  char buf[32];
  int s;

  WiFiClient client = server.client();

  client.write(HEADER, hdrLen);
  client.write(BOUNDARY, bdrLen);

  while (true) {
    if (!client.connected()) break;
    cam.run();
    s = cam.getSize();
    client.write(CTNTTYPE, cntLen);
    sprintf( buf, "%d\r\n\r\n", s );
    client.write(buf, strlen(buf));
    client.write((char *)cam.getfb(), s);
    client.write(BOUNDARY, bdrLen);
  }
}

const char JHEADER[] = "HTTP/1.1 200 OK\r\n" \
                       "Content-disposition: inline; filename=capture.jpg\r\n" \
                       "Content-type: image/jpeg\r\n\r\n";
const int jhdLen = strlen(JHEADER);

// handle_jpg() allows you to access a single jpg taken at
// the time of the request. An example use is like the one
// commented out later in the program, but could be useful.
// Example: server.on("/jpg", HTTP_GET, handle_jpg);
/*void handle_jpg(void) {
  WiFiClient client = server.client();

  cam.run();
  if (!client.connected()) return;

  client.write(JHEADER, jhdLen);
  client.write((char *)cam.getfb(), cam.getSize());
}*/

void handleNotFound() {
  String message = "Server is running!\n\n";
  message += "URI: ";
  message += server.uri();
  message += "\nMethod: ";
  message += (server.method() == HTTP_GET) ? "GET" : "POST";
  message += "\nArguments: ";
  message += server.args();
  message += "\n";
  server.send(200, "text / plain", message);
}

// Add Blynk Virtual Terminal Widget
WidgetTerminal terminal(V0);

// Connection timeout;
#define CON_TIMEOUT   10*1000 // milliseconds

// Not using Deep Sleep on PCB because TPL5110 timer takes over.
#define TIME_TO_SLEEP (uint64_t)60*60*1000*1000   // microseconds

// Camera buffer, URL and picture name
camera_fb_t *fb = NULL;

//Set Strings for the picture name this will be used as the ftp uploaded file name
String pic_name = "Module " + cam_module + " - ";
String sd_pic_name = "Module " + cam_module;  
String pic_url  = ""; //only used for debugging in Blynk app

// Variable marked with this attribute will keep its value during a deep sleep / wake cycle.
RTC_DATA_ATTR uint64_t bootCount = 0;

WidgetRTC rtc;
ESP32_FTPClient ftp (ftp_server, ftp_user, ftp_pass);

void deep_sleep(void);
void FTP_upload(void);
bool take_picture(void);

bool go = false;
bool stop = false;

//LED setup 
int freq = 5000;
int ledCHannel = 1;
int res = 8;
const int ledPin = 4;
int brightness;


BLYNK_CONNECTED() {
  // Synchronize time on connection
  rtc.begin();
  Blynk.virtualWrite(V0, "------------------------------");
  Blynk.virtualWrite(V0, "Module " + cam_module);
  Blynk.virtualWrite(V0, " ");
  Blynk.virtualWrite(V0, "MAC Address:  ");
  Blynk.virtualWrite(V0, WiFi.macAddress());
  Blynk.virtualWrite(V0, " ");
  Blynk.virtualWrite(V0, "IP Address: ");
  Blynk.virtualWrite(V0, ipAddress2String(WiFi.localIP()));
  Blynk.virtualWrite(V0, "------------------------------");
}

// Pin     Blynk Object
//-------------------------------------------
// V0      Terminal
// V5      Shutter (Take Picture Button)
// V10     Flash Slider
// V12     Start Stream Button
// V13     Video Stream
// V14     Stop Stream Button (Must be done from a different module)

void setup() {
  setSyncInterval(30); // RTC sync interval
  ledcSetup(ledCHannel, freq, res);
  ledcAttachPin(ledPin, ledCHannel);
  
  #ifdef DEBUG_ESP
    Serial.begin(115200);
    Serial.setDebugOutput(true);
  #endif

  camera_config_t config;
  config.ledc_channel = LEDC_CHANNEL_0;
  config.ledc_timer   = LEDC_TIMER_0;
  config.pin_d0       = 5;
  config.pin_d1       = 18;
  config.pin_d2       = 19;
  config.pin_d3       = 21;
  config.pin_d4       = 36;
  config.pin_d5       = 39;
  config.pin_d6       = 34;
  config.pin_d7       = 35;
  config.pin_xclk     = 0;
  config.pin_pclk     = 22;
  config.pin_vsync    = 25;
  config.pin_href     = 23;
  config.pin_sscb_sda = 26;
  config.pin_sscb_scl = 27;
  config.pin_pwdn     = 32;
  config.pin_reset    = -1;
  config.xclk_freq_hz = 20000000;
  config.pixel_format = PIXFORMAT_JPEG;

  //init with high specs to pre-allocate larger buffers
  config.frame_size = FRAMESIZE_VGA; // set picture size, FRAMESIZE_XGA = 1024x768
  config.jpeg_quality = 15;          // quality of JPEG output. 0-63 lower means higher quality
  config.fb_count = 1;

//  camera init
//  esp_err_t err = esp_camera_init(&config);
//  if (err != ESP_OK) {
//    Serial.print("Camera init failed with error 0x%x");
//    Blynk.virtualWrite(V0, err);
//    return;
//  }

//  Change extra settings if required
//  sensor_t * s = esp_camera_sensor_get();
//  s->set_vflip(s, 0);       //flip it back
//  s->set_brightness(s, 1);  //up the blightness just a bit
//  s->set_saturation(s, -2); //lower the saturation
  
  // SD CARD INITIALIZE
  if(!SD_MMC.begin()){
    Serial.print("SD Card Mount Failed");
    Blynk.virtualWrite (V0, "SD Card Mount Failed");
    //return;
  }
  
  uint8_t cardType = SD_MMC.cardType();
  if(cardType == CARD_NONE){
    Serial.print("No SD Card attached");
    Blynk.virtualWrite (V0, "No SD Card attached");
  }
  
  // Enable timer wakeup for ESP32 sleep
  esp_sleep_enable_timer_wakeup(TIME_TO_SLEEP);

  Serial.print("ESP Board MAC Address:  ");
  Serial.println(WiFi.macAddress());

  WiFi.begin(ssid, pass);
  Blynk.virtualWrite(V0, "\nConnecting to WiFi");

  while (WiFi.status() != WL_CONNECTED && millis() < CON_TIMEOUT) {
    delay(2000);
    Serial.print(".");
  }

  if (WiFi.isConnected()) {
    Blynk.config(auth);
    Serial.println("IP Address: ");
    Serial.println(WiFi.localIP());
  }

  if (!WiFi.isConnected()) {
    Blynk.virtualWrite(V0, "Failed to connect to WiFi, going to sleep");
    ESP.restart();
  }

  cam.init(config);
  IPAddress ip = WiFi.localIP();
  server.on("/stream", HTTP_GET, handle_jpg_stream); // Could change directory to whatever you want
  // server.on("/jpg", HTTP_GET, handle_jpg); // Uncomment if you would like to access a single jpg
  server.onNotFound(handleNotFound);
  server.begin();
}

// BLYNK virutal pin for led brightness (V10)
//Doesn't seem to work after one of the included libraries
BLYNK_WRITE(V10){
  int pinValue = param.asInt();
  brightness = pinValue;
  Blynk.syncVirtual(V10);
}

//BLYNK virtual pin for shutter "Take Picture" button
BLYNK_WRITE(V5){ 
  int pinValue = param.asInt();
  Serial.println(pinValue);
  go=true;
}

// Convert ip address to a string for use in live stream
String ipAddress2String(const IPAddress& ipAddress) {
  return String(ipAddress[0]) + String(".") +\
  String(ipAddress[1]) + String(".") +\
  String(ipAddress[2]) + String(".") +\
  String(ipAddress[3]); 
}

// Live Stream feed virtual pin and setup
BLYNK_WRITE(V12){
  Blynk.setProperty(V13, "url", ""); //  set the stream url to blank initially
  IPAddress ip = WiFi.localIP();
  String ipaddress = ipAddress2String(ip);
  String streamUrl = "http://" + ipaddress + "/stream";
  delay(1000); // might not be necessary
  // Write url to terminal
  Blynk.virtualWrite(V0, streamUrl);
  // Set the live stream url
  Blynk.setProperty(V13, "url", streamUrl);
  Blynk.syncVirtual(V13);
}

// Button to close/clear live stream url (must be done from different module in  Blynk app)
BLYNK_WRITE(V14){
  Blynk.setProperty(V13, "url", "http://example.com");
}

void loop() {
  Blynk.run();
  ledcWrite(ledCHannel, brightness);
  server.handleClient();
  if (Blynk.connected() && timeStatus() == 2 && go== true) {
    //time_t t = now();

    // Take picture
    if (take_picture()) {
      FTP_upload();
      go = false;
      return;
    } else {
      Blynk.virtualWrite(V0, "Capture failed, sleeping");
      return;
    }
  }
  // Enable deep sleep
  /* if( millis() > CON_TIMEOUT)
  {
    Blynk.virtualWrite(V0, "Timeout");
    deep_sleep();
  }
 */
}

void deep_sleep() {
  Blynk.virtualWrite(V0, "Going to sleep after: " + String( millis() ) + "ms");
  Serial.flush();

  esp_deep_sleep_start();
}

// Get the time in ms
time_t milliSec() { now(); return(millis()); }

bool take_picture() {
  Blynk.virtualWrite(V0, "Taking picture now");
  fb = esp_camera_fb_get();

  if(!fb) {
    Blynk.virtualWrite(V0, "Camera capture failed");
    return false;
  }
  
  // Rename the picture with the time string
  pic_name += String( now() ) + " - " + String(milliSec()) + ".jpg";
  Blynk.virtualWrite (V0, "Camera capture success, saved as:");
  Blynk.virtualWrite (V0, pic_name);

  // ---------------------------------------------
  // ----------- START SD CARD CODE --------------
  // ---------------------------------------------
  
  // initialize EEPROM with predefined size
  EEPROM.begin(EEPROM_SIZE);
  pictureNumber = EEPROM.read(0) + 1;

  // Path where new picture will be saved in SD Card
  String path = "/picture" + String(pictureNumber) +".jpg";

  // Set SD_MMC Object as the file system
  fs::FS &fs = SD_MMC; 
  
  File file = fs.open(path.c_str(), FILE_WRITE);
  if(!file){
    Blynk.virtualWrite(V0, "Failed to open file in writing mode");
  } else {
    file.write(fb->buf, fb->len); // payload (image), payload length
    Blynk.virtualWrite(V0, "Saved file to path: " + String(path));
    EEPROM.write(0, pictureNumber);
    EEPROM.commit();
  }
  file.close();
  return true;
  // ---------------------------------------------
  // ------------- END SD CARD CODE --------------
  // ---------------------------------------------
}

void FTP_upload() {
  Blynk.virtualWrite(V0, "Uploading via FTP");
  ftp.OpenConnection();
  
  //Create a file and write the image data to it;
  ftp.InitFile("Type I");
  //ftp.ChangeWorkDir("/main/images"); // change it to reflect your directory
  const char *f_name = pic_name.c_str();
  ftp.NewFile( f_name );
  ftp.WriteData(fb->buf, fb->len);
  ftp.CloseFile();

  // Change URL on Blynk App
  pic_url += "https://camerafly.app/images/";
  pic_name.replace(" ", "%20");
  pic_url += pic_name;
  Blynk.virtualWrite(V0, "Change App URL to: ");
  Blynk.virtualWrite(V0,  pic_url);
  Blynk.setProperty(V1, "url", cam_module.toInt(), pic_url);

  Blynk.virtualWrite(V0, "restarting...");
  // Breath, without delay URL failed to update.
  delay(100);

  ESP.restart();
}

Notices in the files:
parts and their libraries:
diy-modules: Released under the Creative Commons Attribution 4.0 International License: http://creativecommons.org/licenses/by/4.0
